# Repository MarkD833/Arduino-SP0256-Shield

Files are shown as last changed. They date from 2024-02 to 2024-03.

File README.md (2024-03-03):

# Arduino UNO General Instruments SP0256-AL2 Shield
After playing with the National Semiconductor Digitalker IC, I got to remembering about another speech chip from my younger days. Way back when I owned a [NASCOM-2](https://en.wikipedia.org/wiki/Nascom) Z80 based machine, I also had a speech interface built around a GI SP0256-AL2 device that I hooked up to it. This is my spin on using the SP0256-AL2 chip with a modern-ish Arduino UNO board.

## Description

The aim of this project is to create a shield for an Arduino UNO to bring to life a General Instruments SP0256-AL2 speech IC and to additionall have some non-volatile storage to hold some [allophones](https://en.wikipedia.org/wiki/Allophone) for pre-defined words and phrases.

## Design

In order to speak a word (or phrase), the SP0256-AL2 needs to be passes a stream of allophones that when strung together sound like a word. The SP0256-AL2 has 64 allophones. The required allophone is presented on the pins A1..A8. In this design, A7 & A8 are grounded so only 6 bits are used from the shift register.

Once the required allophone has been presented, the ALD (Address Load) pin is pulsed low briefly. This loads the allophone into the SP0256-AL2 and starts the sound generation process.

The SP0256-AL2 sets the LRQ (Load Request) pin low when it is ready for the next allophone.

### Interface

I've chosen to use the SPI interface of the ATMEGA328P on the UNO and a single 74HCT595 serial-in / parallel-out shift register to transfer the allophone to the SP0256-AL2 chip.

I'm using the SPI signals MOSI and SCK from the ICSP header on the UNO rather than D11 and D13 in the hope that this board can also be used with an Arduino MEGA2560 as well. The SPI signals on the Arduino MEGA2560 board are on completely different pins, but they are also present on the ICSP header in the same physical location as on the UNO.

The SPI SS signal is routed to the D10 pin on the UNO, the Address Load is routed to the A1 pin on the UNO and the Load Request is routed to pin A0 on the UNO.

### Power

Unlike the Digitalker chip, the SP0256-AL2 runs from 5V which is sourced from the UNO board. 

### Audio

The audio circuitry is lifted directly from the SP0256-AL2 datasheet.

# The Arduino UNO Shield

An assembled shield (missing the EEPROM chip).
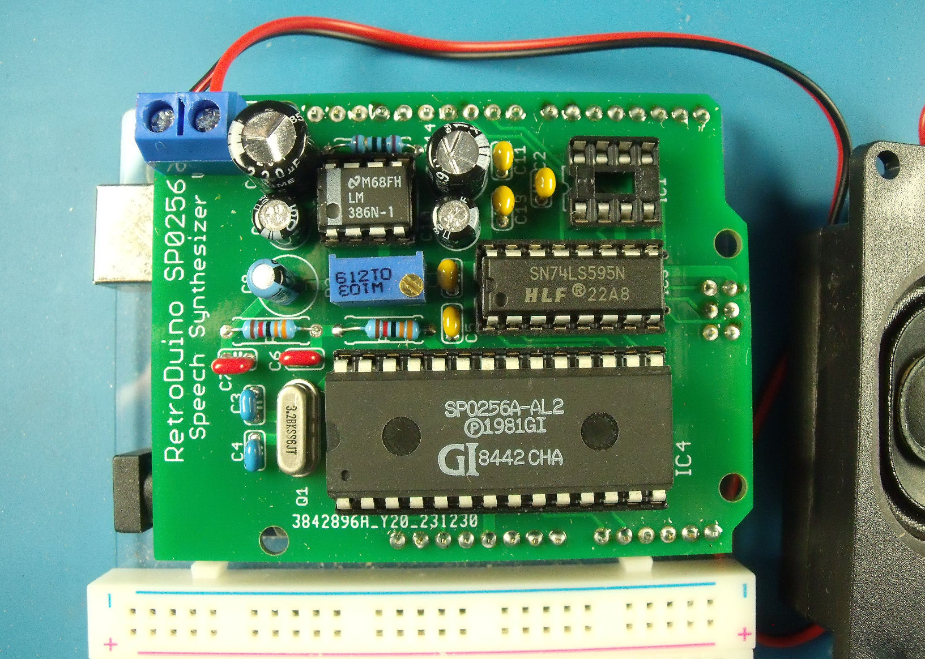
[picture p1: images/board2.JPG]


# Assembly

Start with the discrete components - there are a few resistors and capacitors which should be easy to hand solder. Then add the various IC sockets and the header pins.

The header pins are best inserted into the Arduino UNO board first and then the shield placed on to of them. That way all the headers will be vertical and mate up with the UNO sockets properly.

When you've installed all the basic components, and before fitting any chips, check that you have 5V on the VCC pins of the SP0256-AL2, 74HCT595 and 25LC256.

Install the SP0256-AL2, 74HCT595 and the 25LC256 EEPROM. 

# Speaking the first words

I've created a simple test sketch that you can use to send any of the allophones. It's in the code folder and called ALLOTEST. You can type in either the allophone number (0-63) or the allophone name. Multiple allophones can be generated - simply put a space between each allophone.
 As a start, the allophones for the word "hello" are:
 
> PA2 HH1 EH LL OW PA1

or

> 1 27 7 45 53 0

Note that the SP0256-AL2 needs a silence allophone such as PA1 at the end of a sequence otherwise it continues to output the last sound it made.

# Bored with trying to work out the required allophones yet?

I discovered a [software implementation of the CTS256 chip](https://github.com/GmEsoft/SP0256_CTS256A-AL2). The CTS256 chip is used to convertt plain ASCII character words into the required allophones that the SP0256-AL2 uses. The software can be compiled using the free version of Visual Studio. Once compiled, you can use the CTS256 simulator to produce the required allophones like this:

> CTS256A-AL2.exe hello
>
> CTS256A-AL2(tm) Emulator - v0.0.6-alpha
>
> PA2 HH1 EH LL OW PA3
>
> Conversion complete.

It's not perfect but it does provide a reasonable starting point for creating your own words.

# On-board vocabulary

The board also includes a 25LC256 EEPROM to store pre-defined sequences of allophones that can be read back and transferred to the SP0256-AL2 chip.

## Creating a library of words

It took a little bit of lateral thinking but I discovered that I could use the free online assembler at [ASM80.com](https://asm80.com) to create Intel Hex records.

I've included a sample library of quite a few words in the code folder called vocab_v1.0.asm. The words are mostly the pre-defined words that are available with the National Semiconductor Digitalker Voice Selection Software (DVSS) and were created using a batch file and a slightly modified version of the CTS256A-AL2 program (see above), followed by some search and replace incantations in NotePad++.

This plain text file can be pasted into a new file on asm80.com (I used the 8080 CPU type when creating the new file).

The layout of the EEPROM memory is detailed in the vocabulary file. Simply, there's a list of 16-bit pointers at the start of memory that point to each sequence of allophones required to sound out a particualr word (or phrase). I simply grouped the words so that all words starting with A are together and all words starting with B are together etc.

Address 0000 holds a 16-bit pointer to a null terminated string that you can use to identify your vocabulary.

Starting at address 0002 are the 16-bit pointers to all the words that begin with A. Starting at address 500 (that's 500 decimal) are the 16-bit pointers to all the words that begin with B. Starting at address 1000 are the 16-bit pointers to all the words that begin with C and so on.

That gives 500 bytes (or 250 16-bit pointers => 250 words) to store all the words beginning with a certain letter. With 26 letters in the alphabet and 250 words per letter, that gives a possible maximum of 6500 words.

If you want to add a new word, then simply tag it on to the end of the group of words with the same first letter. That way you don't need to adjust the number associated with any existing word. Well, not unless you end up with more than 250 words with the same first letter! 

The file is then saved and compiled to produce the Intel-Hex file.

## Programming the vocabulary into the EEPROM

I've created a simple test sketch that you can use to program the on-board EEPROM. Or you can use an external programmer to program the chip. The sketch is in the code folder and called EE_PROG.

With the sketch running, you can then upload the vocabulary using a terminal program such as TeraTerm. I used CoolTerm as it will display the output from the sketch as the upload progresses.

*NOTE:* I had to edit the Intel-Hex file generated by ASM80 to insert a final new line so that the end of file record was processed by the EEPROM programming sketch.

## Accesing the EEPROM vocabulary

I've created a simple sketch to recall the words in the vocabulary. The sketch is in the code folder and called EE_TEST.

To speak one of the stored phrases, just type in the phrase index number. To say the word OK, the index number is 3506 in the vocab v1.0 file.

There's very little error checking in the demonstration code so watch out!

Note that I did hope to check to see if the 16-bit pointer was valid before attempting to retrieve the specific allophone sequence. However, being mindful of the number of write cycles of the EEPROM, I couldn't see a way to return all locations back to $FF before programming a new vocabulary without literally writing $FF to every location manually.

I think that there may be some cleverness within the ASM80 directives that I could use to fill the unused sections of the pointer table with $FF. If I find it, I will update the vocab source file and ammend the demo accordingly. As it stands, any memory location of EEPROM that doesn't get written to when loading the new Intel-Hex file will retain whatever value was in there previously.

# Further information

Have a look in the datasheets folder for information on the SP0256-AL2 chip and its companion, the CTS256. The SP0256-AL2 datasheet details the allophones as well as examples of their use in english words.

# Known errors

* The addition of a 10K pull up resistor on the ALD line stops spurious sounds whilst uploading sketches.

* There may be an issue with the code that handles the writing of the Intel-HEX data to the EEPROM. When trying to load the vocabulary Intel-Hex file using the EE_PROG sketch, the data sometimes got messed up such that only partial words were spoken. I've not figured out whether this is a problem with my code or the EEPROM library as the Intel-Hex file is correct.
 
# Releases

* 0.2
    * New demonstrations sketches
    * New large vocabulary file for the EEPROM
* 0.1
    * Initial Release

## License

This project is licensed under the GNU General Public License v3.0 - see the LICENSE.md file for details

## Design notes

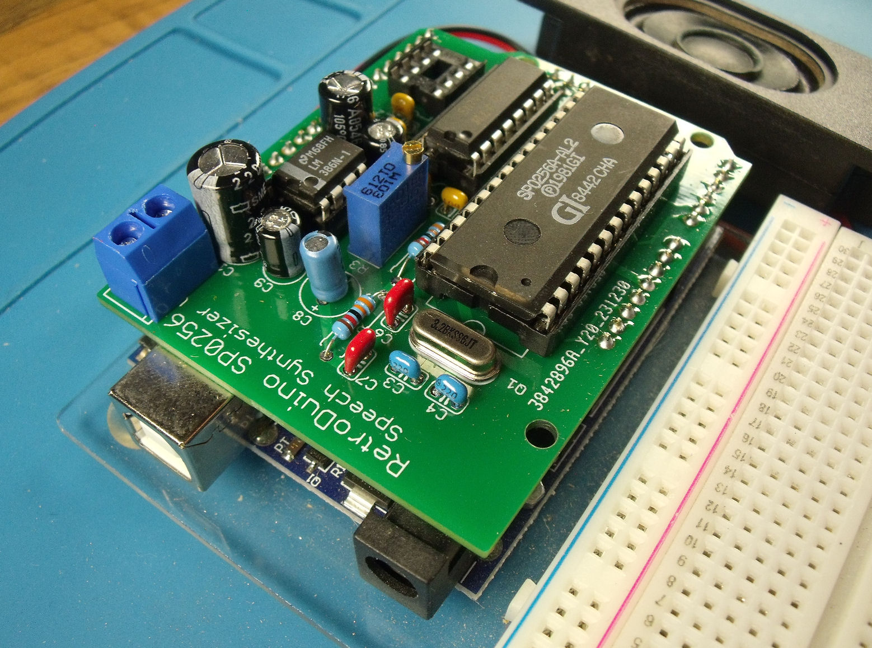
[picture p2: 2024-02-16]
images/board3.JPG

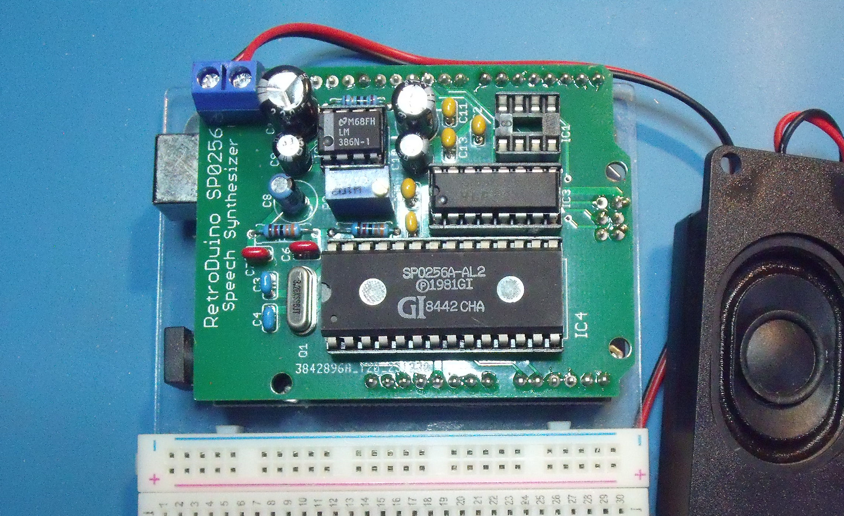
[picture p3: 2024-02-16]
images/board1.JPG

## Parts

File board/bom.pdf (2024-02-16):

Part | Value | Device | Package | Description
B1 | ARDUINO_UNO_R3 ARDUINO_UNO_R3 ARDUINO_R3 | Arduino R3 Footprint with SPI header
C1 | 100n | C-EU025-024X044 | C025-024X044 | CAPACITOR, European symbol
C2 | 100n | C-EU025-024X044 | C025-024X044 | CAPACITOR, European symbol
C3 | 22p | C-EU025-024X044 | C025-024X044 | CAPACITOR, European symbol
C4 | 22p | C-EU025-024X044 | C025-024X044 | CAPACITOR, European symbol
C5 | 100n | C-EU025-024X044 | C025-024X044 | CAPACITOR, European symbol
C6 | 22n | C-EU025-024X044 | C025-024X044 | CAPACITOR, European symbol
C7 | 22n | C-EU025-024X044 | C025-024X044 | CAPACITOR, European symbol
C8 | 1u | CPOL-EUE2.5-7 | E2,5-7 | POLARIZED CAPACITOR, European symbol
C9 | 10u | CPOL-EUE2.5-5 | E2,5-5 | POLARIZED CAPACITOR, European symbol
C10 | 10u | CPOL-EUE2.5-5 | E2,5-5 | POLARIZED CAPACITOR, European symbol
C11 | 100n | C-EU025-024X044 | C025-024X044 | CAPACITOR, European symbol
C12 | 220u | CPOL-EUE2.5-7 | E2,5-7 | POLARIZED CAPACITOR, European symbol
C13 | 100n | C-EU025-024X044 | C025-024X044 | CAPACITOR, European symbol
C14 | 100u | CPOL-EUE2.5-7 | E2,5-7 | POLARIZED CAPACITOR, European symbol
IC1 | 25LC256 | 25LC080P | DIL8 | Serial EEPROM 4K/ 8K , SPI bus
IC2 | LM386N | LM386N-1 | DIL08 | Low Voltage Audio Power Amplifier
IC3 | 74HCT595N | 74HCT595N | DIL16 | 8-bit SHIFT REGISTER, output latch
IC4 | SP0256-AL2 | SP0256-AL2 | DIL28-6-OCT_PADS | General Instrument SP0256-AL2 Speech Synthesizer IC
J1 | CONN_025MM | SCREWTERMINAL-5MM-2 Multi connection point. Often used as Generic Header
Q1 | 3.12MHz | CRYSTALHC49S | HC49/S | CRYSTAL
R1 | 33K | R-EU_0309/10 | 0309/10 | RESISTOR, European symbol
R2 | 33K | R-EU_0309/10 | 0309/10 | RESISTOR, European symbol
R3 | 10K | R-TRIMM3296W | RTRIM3296W | Trimm resistor
R4 | 10R | R-EU_0309/10 | 0309/10 | RESISTOR, European symbol

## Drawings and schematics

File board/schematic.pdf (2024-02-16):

A

A

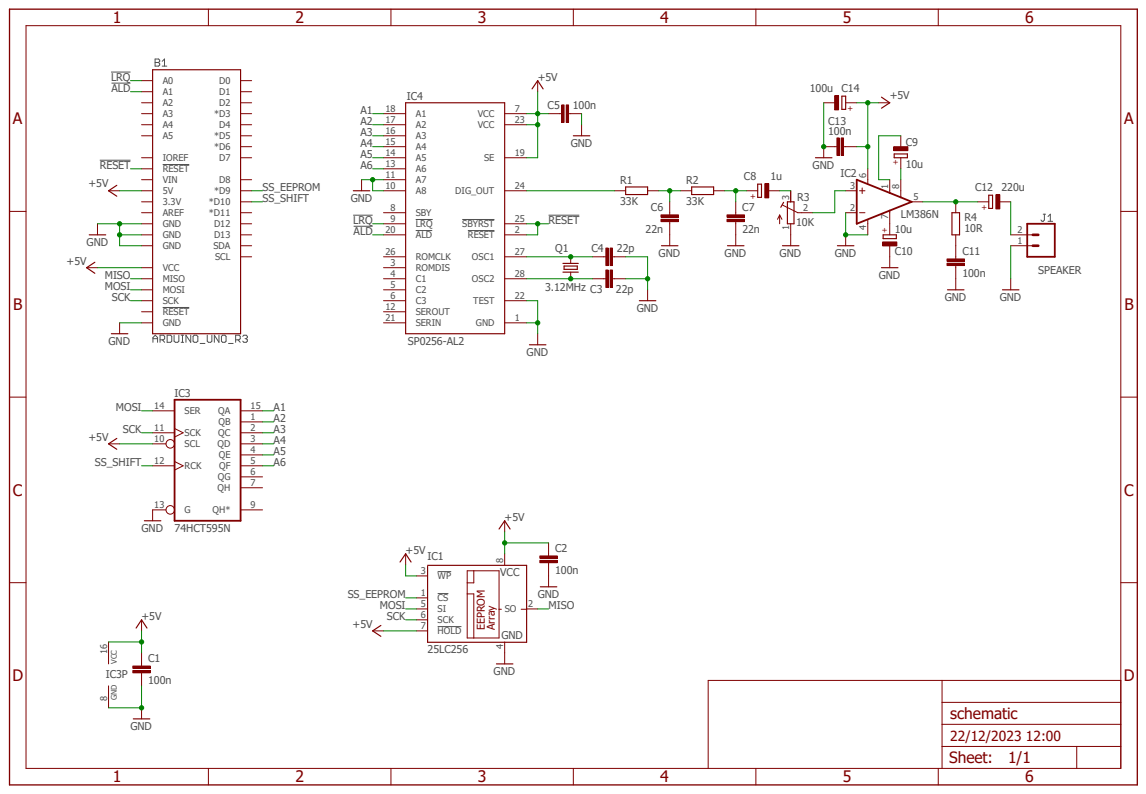
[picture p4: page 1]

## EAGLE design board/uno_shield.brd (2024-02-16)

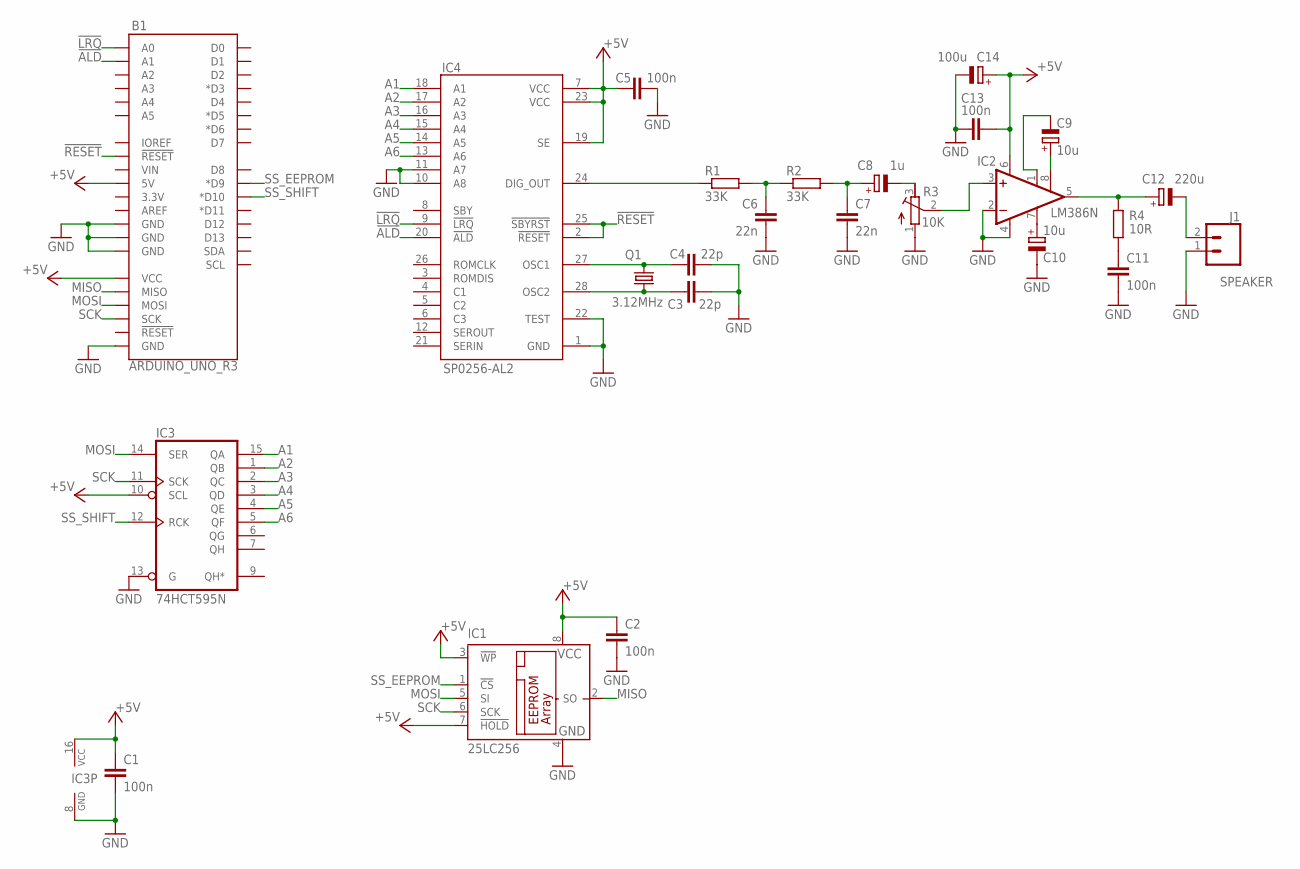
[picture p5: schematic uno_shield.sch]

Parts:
B1: ARDUINO_UNO_R3; ARDUINO_R3
C1, C2, C5, C11, C13: 100n; C025-024X044
C3, C4: 22p; C025-024X044
C6, C7: 22n; C025-024X044
C8: 1u; E2,5-7
C9, C10: 10u; E2,5-5
C12: 220u; E2,5-7
C14: 100u; E2,5-7
IC1: 25LC256; DIL8
IC2: LM386N; DIL08
IC3: 74HCT595N; DIL16
IC4: SP0256-AL2; DIL28-6-OCT_PADS
J1: CONN_025MM; SCREWTERMINAL-5MM-2
Q1: 3.12MHz; HC49/S
R1, R2: 33K; 0309/10
R3: 10K; RTRIM3296W
R4: 10R; 0309/10

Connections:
!ALD: B1.A1, IC4.20 (!ALD)
!LRQ: B1.A0, IC4.9 (!LRQ)
!RESET: B1.RESET@1 (!RESET!), IC4.2 (!RESET), IC4.25 (!SBYRST)
+5V: B1.5V, B1.VCC, C1.1, C2.1, C5.1, C13.2, C14.+, IC1.3 (!WP), IC1.7 (!HOLD), IC1.8 (VCC), IC2.6 (VS), IC3.10 (SCL), IC3.16 (VCC), IC4.7 (VCC), IC4.19 (SE), IC4.23 (VCC)
A1: IC3.15 (QA), IC4.18 (A1)
A2: IC3.1 (QB), IC4.17 (A2)
A3: IC3.2 (QC), IC4.16 (A3)
A4: IC3.3 (QD), IC4.15 (A4)
A5: IC3.4 (QE), IC4.14 (A5)
A6: IC3.5 (QF), IC4.13 (A6)
GND: B1.GND@1 (GND), B1.GND@2 (GND), B1.GND@3 (GND), B1.GND@4 (GND), C1.2, C2.2, C3.2, C4.2, C5.2, C6.2, C7.2, C10.-, C11.2, C13.1, C14.-, IC1.4 (GND), IC2.2 (-IN), IC2.4 (GND), IC3.8 (GND), IC3.13 (G), IC4.1 (GND), IC4.10 (A8), IC4.11 (A7), IC4.22 (TEST), J1.1, R3.1 (A)
MISO: B1.MISO, IC1.2 (SO)
MOSI: B1.MOSI, IC1.5 (SI), IC3.14 (SER)
unnamed: IC4.24 (DIG_OUT), R1.1
unnamed: C3.1, IC4.28 (OSC2), Q1.1
unnamed: C4.1, IC4.27 (OSC1), Q1.2
unnamed: C6.1, R1.2, R2.1
unnamed: C7.1, C8.+, R2.2
unnamed: C8.-, R3.3 (E)
unnamed: C9.-, IC2.1 (GAIN)
unnamed: C9.+, IC2.8 (GAIN)
unnamed: C10.+, IC2.7 (BYPASS)
unnamed: C11.1, R4.1
unnamed: C12.+, IC2.5 (OUT), R4.2
unnamed: C12.-, J1.2
unnamed: IC2.3 (+IN), R3.2 (S)
SCK: B1.SCK, IC1.6 (SCK), IC3.11 (SCK)
SS_EEPROM: B1.D9 (*D9), IC1.1 (!CS)
SS_SHIFT: B1.D10 (*D10), IC3.12 (RCK)

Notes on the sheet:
SPEAKER

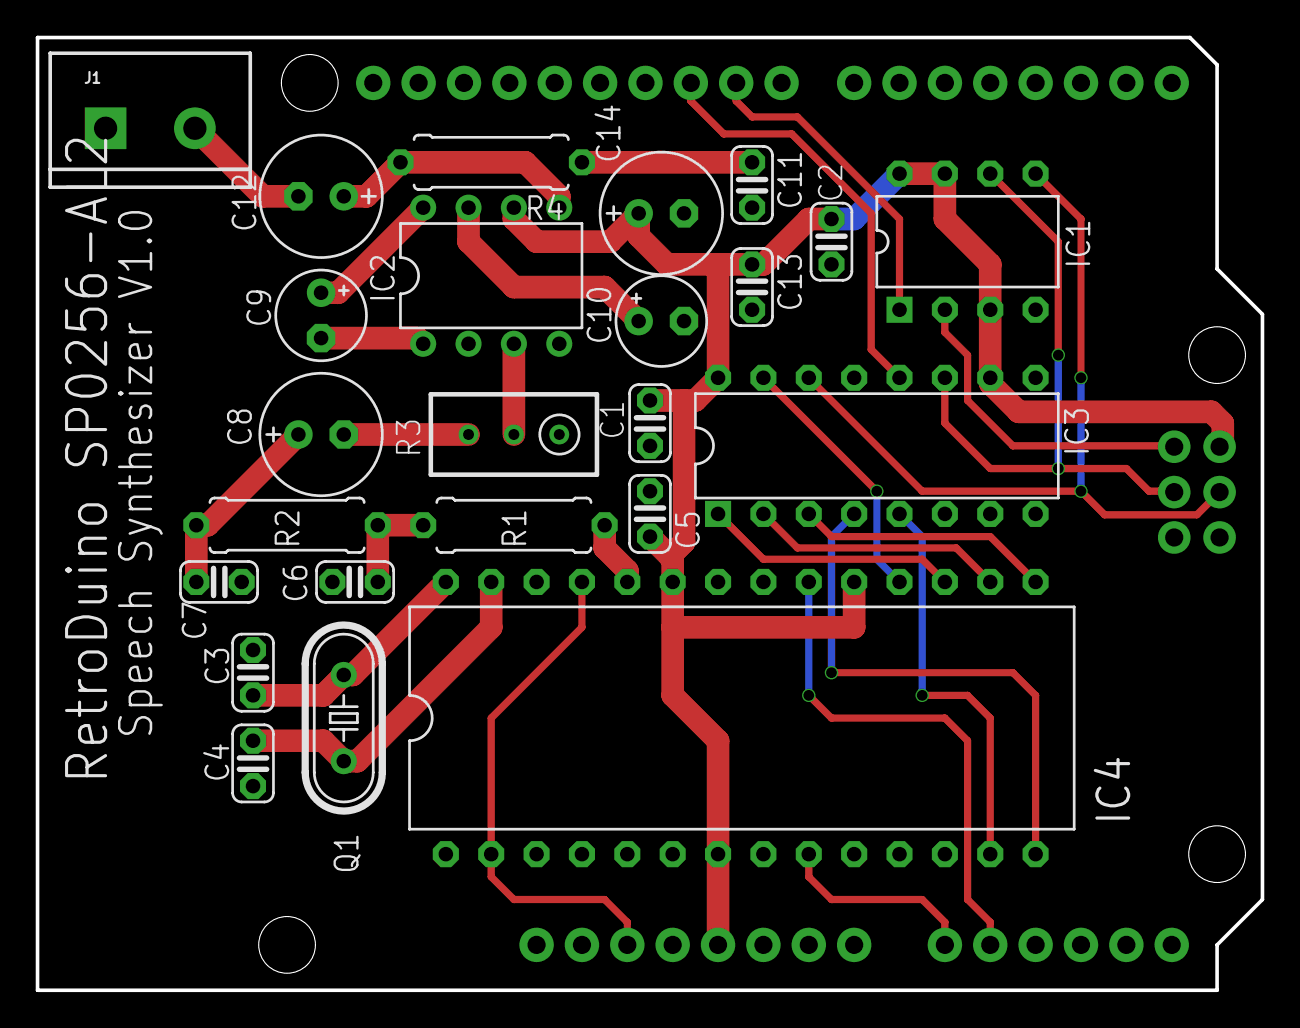
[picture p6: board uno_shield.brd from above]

Board: 2 copper layers, 68.6 x 53.3 mm, 25 parts (0 on the bottom side), 29 nets.

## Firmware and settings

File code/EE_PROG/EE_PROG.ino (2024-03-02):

// =========================================================================
// Arduino UNO General Instruments SP0256-AL2 Shield Project
// https://github.com/MarkD833/Arduino-SP0256-Shield
//
// Onboard 25LC256 EEPROM programming sketch.
//
// =========================================================================
// Uses the EEPROM_SPI_WE library - find it via library manager
// =========================================================================

#include <stdio.h>
#include <SPI.h>
#include <EEPROM_SPI_WE.h>

// maximum number of chars in received text string
#define MAXCHARS    128

// the 25LC256 EEPROM is selected using pin D9 on the UNO
#define EEPROM_SPI_SS 9

// SP0256-AL2 write pulse (output) is on pin A1 on the UNO
#define SP_WRITE  A1

// the 74HCT595 shift registers are selected using pin D10 on the UNO
#define SP0256_SPI_SS 10

EEPROM_SPI_WE myEE = EEPROM_SPI_WE( EEPROM_SPI_SS );

char rxCharBuff[ MAXCHARS ];
uint8_t loadErrors = 0;

void setup() {
  Serial.begin( 9600 );
  Serial.println(F("\n\n========================================================="));
  Serial.println(F("Arduino UNO General Instruments SP0256-AL2 Shield Project"));
  Serial.println(F("  [ https://github.com/MarkD833/Arduino-SP0256-Shield ]\n"));
  Serial.println(F("          SP0256-AL2 25LC256 Programmer V1.0"));
  Serial.println(F("\n========================================================="));

  Serial.println(F("\nNOTE: Leave the baud rate at 9600 as there's no handshaking on the Intel-HEX upload.\n"));

  // congifure the SPI SS pin for the external EEPROM
  pinMode( EEPROM_SPI_SS, OUTPUT );
  digitalWrite( EEPROM_SPI_SS, HIGH );

  SPI.begin();

  // shuts the SP0256 up if it was speaking
  spSpeak( 0 );

  // initialise the external EEPROM interface
  if(myEE.init()){
    Serial.println("EEPROM connected");
    myEE.setPageSize(EEPROM_PAGE_SIZE_64);
  }
  else{
    Serial.println("EEPROM does not respond");
    while(1);
  }  
  delay( 100 );
  Serial.println(F("Waiting for Intel-HEX records."));
}

void loop() {
  char * tok;
  uint16_t phrase;

  // process any serial commands received
  waitForUserInput();

  if ( rxCharBuff[ 0 ] == ':' ) {
    // it's a line of Intel-Hex data so take care of it
    decodeIntelHex();
  }
}

// =========================================================================
// spSpeak - writes a single allophone to the SP0256-AL2 chip
// =========================================================================
void spSpeak( uint8_t alloNumber )
{
  SPI.beginTransaction(SPISettings(4000000, MSBFIRST, SPI_MODE0));
  digitalWrite( SP0256_SPI_SS, LOW );
  SPI.transfer( alloNumber );
  digitalWrite( SP0256_SPI_SS, HIGH );
  SPI.endTransaction();
  
  digitalWrite( SP_WRITE, LOW );
  delay( 1 );
  digitalWrite( SP_WRITE, HIGH );
}


// =========================================================================
// isPrintableChar - Returns TRUE if character is 0..9 or A..Z
// =========================================================================
bool isPrintableChar( char ch ) {
  if ( (ch>='0') || (ch<='9') ) return true;
  if ( (ch>='A') || (ch<='Z') ) return true;
  if ( (ch>='a') || (ch<='z') ) return true;

  return false;
}

// =========================================================================
// waitForUserInput - Wait for the user to type something collecting chars
//                    until ENTER pressed
// =========================================================================
void waitForUserInput() {
  static byte ndx = 0;
  char endMarker = '\n';
  char rc;
  bool newData = false;

  memset(rxCharBuff, 0, MAXCHARS );
  
  while ( newData == false ) {
    if (Serial.available() > 0) {
      rc = Serial.read();

      if (rc != endMarker) {
        if ( isPrintableChar( rc ) == true ) {
          rxCharBuff[ndx++] = rc;
          if (ndx >= MAXCHARS) ndx = MAXCHARS - 1;
        }
      }
      else {
        if ( ndx > 0 ) {
          rxCharBuff[ndx] = '\0';
          ndx = 0;
          newData = true;
        }
      }
    }
  }
}

// =========================================================================
// decodeASCIIHexChar - convert ASCII HEX digit to binary
// =========================================================================
int16_t decodeASCIIHexChar( char ch ) {
    if (ch >= '0' && ch <= '9')
        return ch - '0';
    else if (ch >= 'a' && ch <= 'f')
        return 10 + ch - 'a';
    else if (ch >= 'A' && ch <= 'F')
        return 10 + ch - 'A';
    else
        return -1;
}

// =========================================================================
// decodeIntelHex - decode 1 line of Intel-Hex data held in rxCharBuff[]
// and write it to the external EEPROM.
// =========================================================================
void decodeIntelHex() {
  uint8_t  byteCount = 0;
  uint8_t  checksum = 0;
  uint8_t  tByte = 0;
  uint8_t  buffIndx = 1;
  uint16_t startAddress = 0;
  uint8_t  endOfFile = 0;
  
  // byte count
  byteCount = decodeASCIIHexChar( rxCharBuff[buffIndx++] );
  byteCount = ( byteCount << 4 ) + decodeASCIIHexChar( rxCharBuff[buffIndx++] );
  checksum = byteCount;

  // simple sanity check - knowing byte count means we know how many chars there should be
  if ( strlen( rxCharBuff ) < ( 10 + ( byteCount << 1 ))) {
    Serial.println(F("ERR: Corrupted iHex record."));
    return 1;
  }

  // start address
  tByte = decodeASCIIHexChar( rxCharBuff[buffIndx++] );
  tByte = ( tByte << 4 ) + decodeASCIIHexChar( rxCharBuff[buffIndx++] );
  checksum = checksum + tByte;
  startAddress = tByte;
  tByte = decodeASCIIHexChar( rxCharBuff[buffIndx++] );
  tByte = ( tByte << 4 ) + decodeASCIIHexChar( rxCharBuff[buffIndx++] );
  checksum = checksum + tByte;
  startAddress = ( startAddress << 8 ) + tByte;

  Serial.print( startAddress, HEX );

  // record type - either 00 (Data) or EOF (01)
  tByte = decodeASCIIHexChar( rxCharBuff[buffIndx++] );
  tByte = ( tByte << 4 ) + decodeASCIIHexChar( rxCharBuff[buffIndx++] );
  checksum = checksum + tByte;

  // if record type is 00 (Data) then carry on extracting the bytes
  if ( tByte == 0 ) {
    // enable EEPROM continuous writes
    myEE.continuousPutEnable( startAddress );

    for (uint8_t i=0; i<byteCount; i++) {
      tByte = decodeASCIIHexChar( rxCharBuff[buffIndx++] );
      tByte = ( tByte << 4 ) + decodeASCIIHexChar( rxCharBuff[buffIndx++] );
      checksum = checksum + tByte;

      // write out the byte
      myEE.continuousPut( tByte );
    }
    // done
    myEE.continuousPutDisable();
  }
  else if ( tByte == 1 ) {
    // end of file record
    endOfFile = 1;
  }
  
  // now add in the checksum
  tByte = decodeASCIIHexChar( rxCharBuff[buffIndx++] );
  tByte = ( tByte << 4 ) + decodeASCIIHexChar( rxCharBuff[buffIndx++] );
  checksum = checksum + tByte;

  // if the checksum is ZERO, then we've got a valid record
  if ( checksum == 0 ) {
    // valid record
    Serial.println(F(" - Ok"));
  }
  else {
    // invalid record - checksum failed
    Serial.println(F(" - Checksum fail"));
    loadErrors++;
  }

  if ( endOfFile == 1 ) {
    delay( 1000 );
    if ( loadErrors == 0 ) {
      Serial.println(F("LOAD COMPLETE - NO ERRORS."));
    } else {
      Serial.println(F("LOAD FAILED - ERRORS DETECTED."));
      // reset the error count ready for next attempt
      loadErrors = 0;
    }
  }
}

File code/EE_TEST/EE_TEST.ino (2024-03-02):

// =========================================================================
// Arduino UNO General Instruments SP0256-AL2 Shield Project
// https://github.com/MarkD833/Arduino-SP0256-Shield
//
// Simple EEPROM vocabulary test sketch
//
// =========================================================================
// Uses the EEPROM_SPI_WE library - find it via library manager
// =========================================================================

#include <stdio.h>
#include <SPI.h>
#include <EEPROM_SPI_WE.h>

// maximum number of chars in received text string
#define MAXCHARS    128

// the 74HCT595 shift registers are selected using pin D10 on the UNO
#define SP0256_SPI_SS 10

// the 25LC256 EEPROM is selected using pin D9 on the UNO
#define EEPROM_SPI_SS 9

// SP0256-AL2 load request (input) is on pin A0 on the UNO
#define SP_LOAD_REQ  A0

// SP0256-AL2 write pulse (output) is on pin A1 on the UNO
#define SP_WRITE  A1

// the 74HCT595 shift registers are selected using pin D10 on the UNO
#define SP0256_SPI_SS 10

#define MAXALLO   64

const char table[ MAXALLO ][4] = {
  {"PA1"},  {"PA2"},  {"PA3"},  {"PA4"},  {"PA5"},  {"OY\0"}, {"AY\0"}, {"EH\0"},
  {"KK3"},  {"PP\0"}, {"JH\0"}, {"NN1"},  {"IH\0"}, {"TT2"},  {"RR1"},  {"AX\0"},
  {"MM\0"}, {"TT1"},  {"DH1"},  {"IY\0"}, {"EY\0"}, {"DD1"},  {"UW1"},  {"AO\0"},
  {"AA\0"}, {"YY2"},  {"AE\0"}, {"HH1"},  {"BB1"},  {"TH\0"}, {"UH\0"}, {"UW2"},
  {"AW\0"}, {"DD2"},  {"GG3"},  {"VV\0"}, {"GG1"},  {"SH\0"}, {"ZH\0"}, {"RR2"},
  {"FF\0"}, {"KK2"},  {"KK1"},  {"ZZ\0"}, {"NG\0"}, {"LL\0"}, {"WW\0"}, {"XR\0"},
  {"WH\0"}, {"YY1"},  {"CH\0"}, {"ER1"},  {"ER2"},  {"OW\0"}, {"DH2"},  {"SS\0"},
  {"NN2"},  {"HH2"},  {"OR\0"}, {"AR\0"}, {"YR\0"}, {"GG2"},  {"EL\0"}, {"BB2"}
};

EEPROM_SPI_WE myEE = EEPROM_SPI_WE( EEPROM_SPI_SS );

char rxCharBuff[ MAXCHARS ];

void setup() {
  Serial.begin( 9600 );
  Serial.println(F("\n\n========================================================="));
  Serial.println(F("Arduino UNO General Instruments SP0256-AL2 Shield Project"));
  Serial.println(F("  [ https://github.com/MarkD833/Arduino-SP0256-Shield ]\n"));
  Serial.println(F("      SP0256-AL2 EEPROM Vocabulary Test Sketch V1.0"));
  Serial.println(F("\n========================================================="));

  // congifure the SPI SS pin for the external EEPROM
  pinMode( EEPROM_SPI_SS, OUTPUT );
  digitalWrite( EEPROM_SPI_SS, HIGH );

  // configure the SPI SS pin for the shift registers
  pinMode( SP0256_SPI_SS, OUTPUT );
  digitalWrite( SP0256_SPI_SS, HIGH );

  // configure the write strobe pin to the SP0256-AL2 chip
  pinMode( SP_WRITE, OUTPUT );
  digitalWrite( SP_WRITE, HIGH );

  // configure the LOAD request pin from the SP0256-AL2 chip
  pinMode( SP_LOAD_REQ, INPUT );

  SPI.begin();

  // shuts the SP0256 up if it was speaking
  spSpeak( 0 );

  // initialise the external EEPROM interface
  if(myEE.init()){
    Serial.println("25LC256 EEPROM connected");
    myEE.setPageSize(EEPROM_PAGE_SIZE_64);
  }
  else{
    Serial.println("EEPROM does not respond");
    while(1);
  }

  Serial.print(F("Version string from EEPROM is: "));
  spEEVersion();
  
  Serial.println(F("\n\nEnter 1 or more vocabulary index numbers separated by a space."));
  Serial.println(F("To say the word OK, the index number is 3506 in the current vocaulary."));
}

void loop() {
  char * tok;
  uint16_t vocabIndex;

  // process any serial commands received
  waitForUserInput();

  if ( strlen( rxCharBuff ) > 0 ) {

    tok = strtok( rxCharBuff, " " );
    while ( tok != 0 ) {
      // get the index number
      vocabIndex = atoi( tok );

      Serial.println( vocabIndex );
      spEESpeak( vocabIndex );

      // now wait for the word/phrase to be output
      while ( digitalRead( SP_LOAD_REQ ) == HIGH );

      // and find the next index number
      tok = strtok( 0, " " );
    }

    // finished speaking so wait for the last allophone to complete    
    while ( digitalRead( SP_LOAD_REQ ) == HIGH );
    spSpeak( 0 );
    Serial.println( " -- done -- " );
  }
}

// =========================================================================
// spSpeak - writes a single allophone to the SP0256-AL2 chip
// =========================================================================
void spSpeak( uint8_t alloNumber )
{
  SPI.beginTransaction(SPISettings(4000000, MSBFIRST, SPI_MODE0));
  digitalWrite( SP0256_SPI_SS, LOW );
  SPI.transfer( alloNumber );
  digitalWrite( SP0256_SPI_SS, HIGH );
  SPI.endTransaction();
  
  digitalWrite( SP_WRITE, LOW );
  delay( 1 );
  digitalWrite( SP_WRITE, HIGH );
}

// =========================================================================
// spEESpeak - writes a stored sequence of allophones from the 25LC256
//             EEPROM to the SP0256-AL2 chip
// =========================================================================
void spEESpeak( uint16_t indx ) {
  uint16_t lutAddr = 0;
  uint16_t lsbAddr = 0;
  uint16_t alloAddr = 0;
  uint8_t  i = 0;
  uint8_t  j = 0;

  uint8_t  allo = 0;
  
  // calculate the address in the look up table where message pointer is 
  lutAddr = indx << 1;
/*   
  SPI.beginTransaction(SPISettings(4000000, MSBFIRST, SPI_MODE0));
  digitalWrite( EEPROM_SPI_SS, LOW );
  SPI.transfer( EEREAD_CMD );
  SPI.transfer16( lutAddr );

  lsbAddr = SPI.transfer( 0 );
  alloAddr = SPI.transfer( 0 );
  alloAddr = ( alloAddr << 8 ) | lsbAddr;
  
  digitalWrite( EEPROM_SPI_SS, HIGH );
*/
  Serial.print(F("message start = "));
  Serial.println( lutAddr , HEX );
/*  
  // alloAddr now holds the address in the EEPROM where the sequence of allophones starts
  // read out the allophones starting at that address until 0xFF is found (i.e. end of sequence)
  digitalWrite( EEPROM_SPI_SS, LOW );
  SPI.transfer( EEREAD_CMD );
  SPI.transfer16( alloAddr );
  do {
    rxCharBuff[ i ] = SPI.transfer( 0 );
    Serial.println( rxCharBuff[i], HEX );
    if ( rxCharBuff[ i ] == -1 ) break;
    i++;
  } while ( i < MAXCHARS );
  digitalWrite( EEPROM_SPI_SS, HIGH );

  SPI.endTransaction();
*/
  lsbAddr = myEE.read( lutAddr++ );
  alloAddr = myEE.read( lutAddr );
  alloAddr = ( alloAddr << 8 ) | lsbAddr;

  do {
    allo = myEE.read( alloAddr++ );
    if ( allo != 0xFF ) {
      Serial.println( table[ allo ] );
      spSpeak( allo );

      // now wait for the sound to be output
      while ( digitalRead( SP_LOAD_REQ ) == HIGH );
    }
  } while ( allo != 0xFF );
/*
  for (j=0; j<i; j++) {
    spSpeak( rxCharBuff[j] );
    // now wait for the sound to be output
    while ( digitalRead( SP_LOAD_REQ ) == HIGH );
  }
  Serial.println( i, HEX );
*/
}
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

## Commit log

2024-02-18 added sample vocabulary
2024-02-18 added note re Arduino EEPROM library
2024-03-02 New demo sketches
    Replaced the demo sketches and updated the large vocabulary.
    [ALLOTEST.ino, EE_PROG.ino, EE_TEST.ino]
2024-03-03 corrected cut and paste frenzy!

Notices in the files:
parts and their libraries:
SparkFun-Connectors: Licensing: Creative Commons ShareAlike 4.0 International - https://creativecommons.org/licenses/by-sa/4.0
